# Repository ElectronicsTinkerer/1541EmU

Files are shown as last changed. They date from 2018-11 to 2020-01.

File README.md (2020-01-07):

# 1541EmU
Source code and eagle files for the 1541 Emulator
<hr>

 _Description_
 
  The 1541EmU is a 1541 emulator for the c64. It is based on the ATMEGA328P-PU and interfaces over the IEC bus. Files are stored on a micro SD card formatted to FAT32 using the 8.3 file name format. Included is a drive reset button that resets the drive, but not the computer. There is also a solder jumper to enable reset-by-computer, which allows the c64's reset line to reset the drive.
 <br> 
 I have a demo <a href="https://youtu.be/4uivsbCX4fI">here</a>. (https://youtu.be/4uivsbCX4fI)
  
 _Features_
 
  * Save and load files with almost any filename (ASCII Characters only)
  * Change file order on disk (Through a computer)
  * <code>LOAD "*",8</code> is allowed
  * View directory
  * Overwrite existing files on disk
  * Auto initialization of filename translation file (DIR)
  * Cassette interface pass through connector.
  * ICSP and Tx/Rx headers
  * Power and status LEDs
  * Compatible with the Arduino IDE

# Board
Latest board revision: 1.1 on September 9, 2018
  (Note: there is no official revision 1.0)
  
  1) Checked schematic, part numbers, and part footprint sizing.
  2) Fixed board dimension issue
  
# Source
Latest revision: EFS1.00 (Extended File System v1.00) on October 23, 2018
  
  1) Added the "DIR" file that translates the expected filename from the c64 to the actual name that is stored on the SD
  2) Fixed "DEVICE NOT PRESENT ERROR" (as far as I can test the drive)

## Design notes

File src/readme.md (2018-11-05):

Included in the /src directory are the various revisions of the source for the 1541EmU.

The latest revision is EFS v1.00

In the /src/EFS1.00 directory is an example DIR file in addition to the arduino source

Revision history is below (Newest to Oldest):

	EFS1.00

	v3.25

	v2.18 (Contains part of v1.00 at bottom comments)

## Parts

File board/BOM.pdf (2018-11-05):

BOM

Page 1

Part | Unit Price | Total Price Number Needed | Notes:
Connectors
CEC* | $1.40 | 5 | $6.99 | 1 | Card edge connector, 2x6, 3.96mm spacing | Also can use these: 387-012-523-300
DIN 6 | $1.40 | 5 | $6.99 | 1 | DIN 6 connector, male
RJ11 Male | $0.10 | 100 | $9.99 | 1 | | https://www.amazon.com/dp/B06XV7J3KZ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
523-RJE01J4001 | $0.51 | 10 | $5.10 | 1 | RJ11 Female (**CHECK**) | https://www.mouser.com/ProductDetail/Amphenol-Commercial-Products/RJE01J4001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

Sockets
571-1-2199298-9 | $0.60 | 10 | $6.03 | 1 | 28 Pin DIP socket, 7.62 Row Spacing, 2.54 Pitch | https://www.mouser.com/ProductDetail/TE-Connectivity/1-2199298-9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
47334-0001 | $3.15 | 1 | $3.15 | 1 | MicroSD Holder, Push-Push, SMD | https://www.mouser.com/ProductDetail/Molex/47334-0001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

IC
LP2950-33LPRE3 | $0.38 | 10 | $3.76 | 1 | 3.3v REG | https://www.mouser.com/ProductDetail/Texas-Instruments/LP2950-33LPRE3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
ATMEGA328P-PU | $2.14 | 5 | $10.70 | 1 | Main controler, DIP28 | https://www.mouser.com/ProductDetail/Microchip-Technology-Atmel/ATMEGA328P-PU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

Passive
ULD1H2R2MDD1TD | $0.09 | 100 | $9.00 | 1 | 2.2uF | https://www.mouser.com/ProductDetail/Nichicon/ULD1H2R2MDD1TD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
USP1HR22MDD | $0.21 | 10 | $2.07 | 2 | 0.22uF | https://www.mouser.com/ProductDetail/Nichicon/USP1HR22MDD?qs=%2fha2pyFadujuMoPc7crJw6l9tVyhaXQnGDLoTOhhVrE%3d
K220J10C0GF5UH5 | $0.04 | 50 | $1.75 | 2 | 22pF | https://www.mouser.com/ProductDetail/Vishay-BC-Components/K220J10C0GF5UH5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
OJ4715E-R52 | $0.01 | 100 | $1.00 | 2 | 470 Ohm | https://www.mouser.com/ProductDetail/Ohmite/OJ4715E-R52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
299-2.2K-RC | $0.12 | 1 | $0.12 | 3 | 2.2k Ohm | https://www.mouser.com/ProductDetail/Xicon/299-22K-RC?qs=sGAEpiMZZMu61qfTUdNhGzmcydQ1pJoanehw0NWTJkc%3d
299-3.3K-RC | $0.12 | 1 | $0.12 | 3 | 3.3k Ohm | https://www.mouser.com/ProductDetail/Xicon/299-33K-RC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
299-4.7K-RC | $0.01 | 200 | $2.20 | 3 | 4.7k Ohm | https://www.mouser.com/ProductDetail/Xicon/299-47K-RC?qs=sGAEpiMZZMu61qfTUdNhG%2fbdyz6pU6a%252bfqpVSzaacno%3d
299-1M-RC | $0.12 | 1 | $0.12 | 1 | 1M Ohm | https://www.mouser.com/ProductDetail/Xicon/299-1M-RC?qs=sGAEpiMZZMu61qfTUdNhG1aMK7XKB77EzBMns1d2vjU%3d
LFXTAL027945Bulk | $0.18 | 1 | $0.18 | 1 | 16MHz Crystal | https://www.mouser.com/ProductDetail/IQD/LFXTAL027945Bulk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
833-1N914B-TP | $0.18 | 100 | $2.70 | 1 | Diode for reset 1N914 | https://www.mouser.com/ProductDetail/Micro-Commercial-Components-MCC/1N914B-TP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

Indicators
859-LTL-1CHEE | $0.06 | 100 | $6.40 | 1 | Red LED | https://www.mouser.com/ProductDetail/Lite-On/LTL-1CHEE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
859-LTL-1CHG | $0.06 | 100 | $6.40 | 1 | Green LED | https://www.mouser.com/ProductDetail/Lite-On/LTL-1CHG?qs=sGAEpiMZZMuCm2JlHBGefiNuiN6kU%2fJslYHv14s%2f9OY%3d

Misc
Wire | $0.17 | 33 | $5.45 | 1 | Assuming 9" used per unit | https://www.amazon.com/Bistras-Telephone-Extension-Machine-Answering/dp/B075JRX7XK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
SPST Pushbutton | $0.19 | 10 | $1.86 | 1 | Reset Switch | https://www.mouser.com/ProductDetail/Panasonic/EVQ-PAC05R/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
Screw | | | | 2 | Standoff
Nut | | | | 4 | Standoff
Rubber Foot | | | | 2 | Standoff

Board
85x40mm | $1.90 | 10 | $19.00 | 1 | PCB Board, Green Soldermask
Total | $13.13 | 963 | $111.08 | $13.88

Number
Purchased

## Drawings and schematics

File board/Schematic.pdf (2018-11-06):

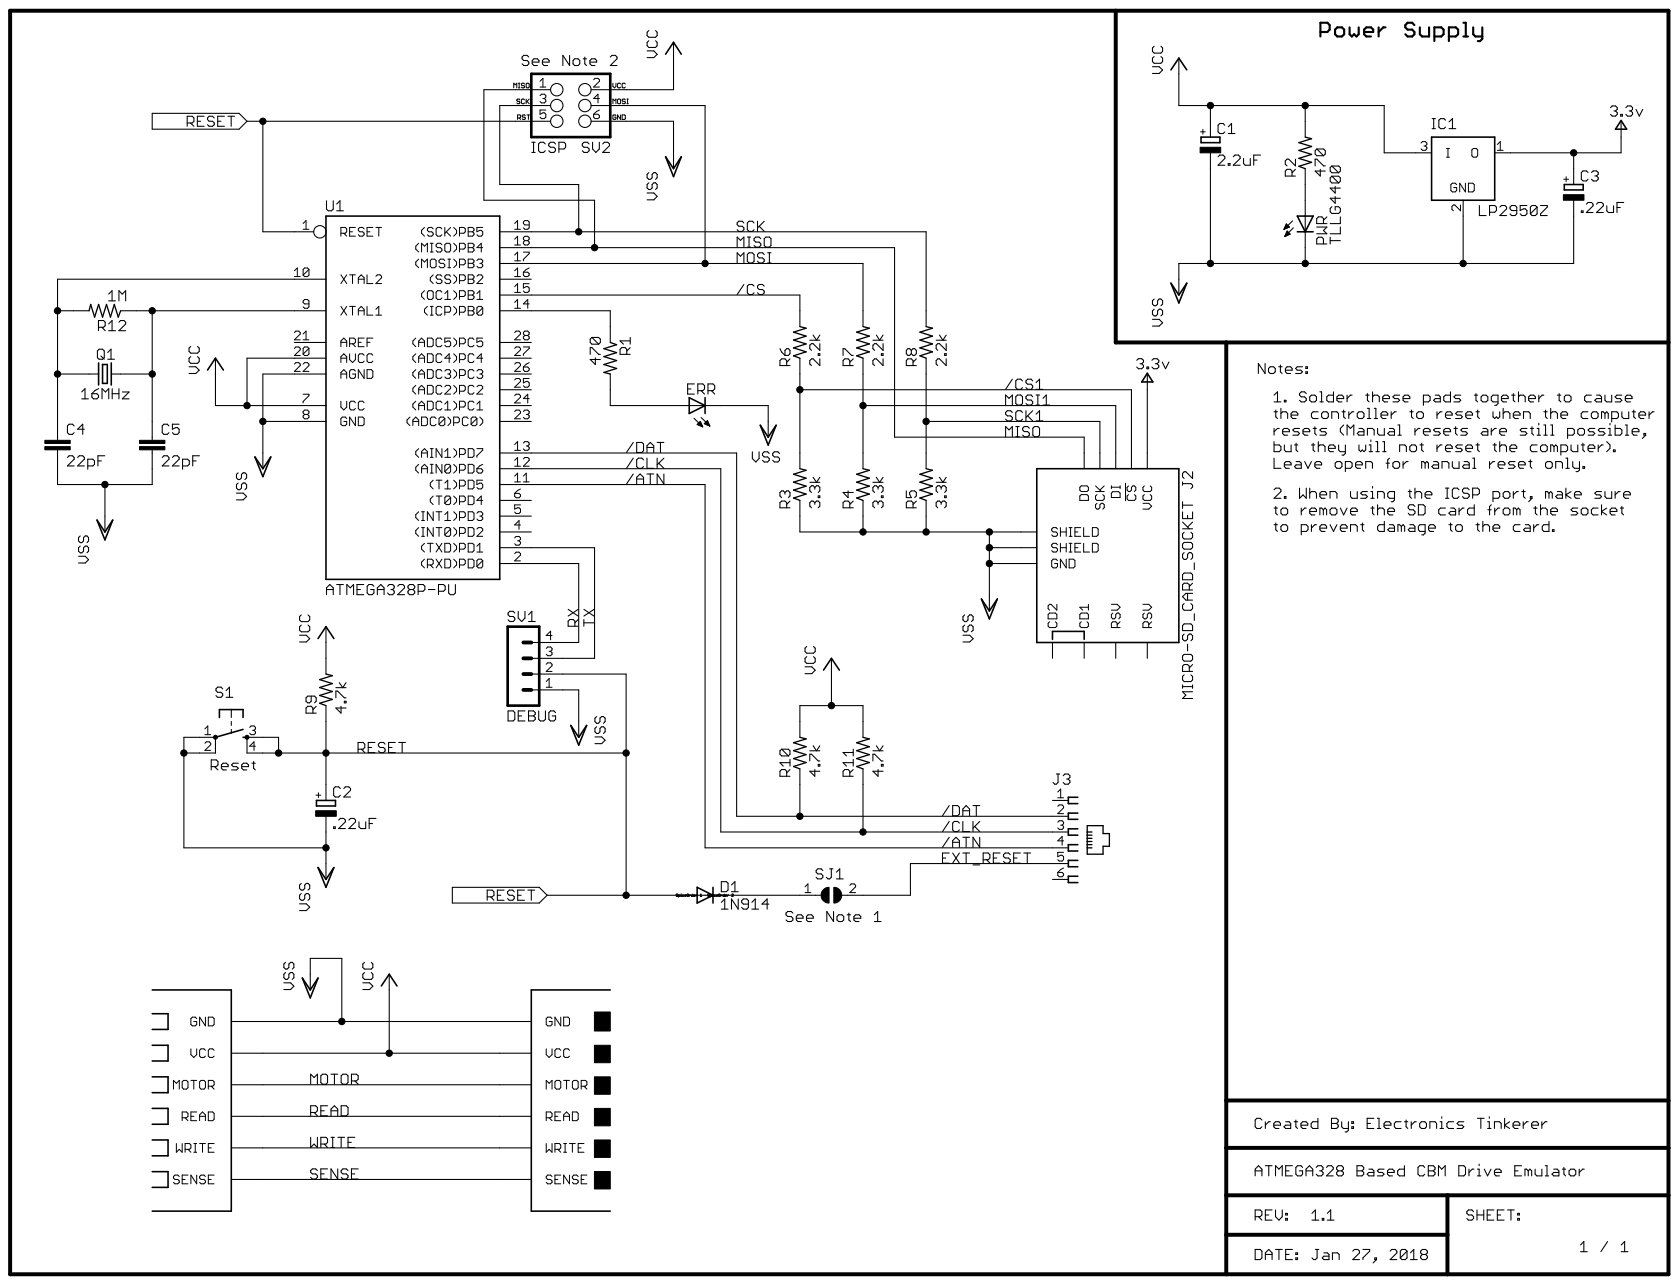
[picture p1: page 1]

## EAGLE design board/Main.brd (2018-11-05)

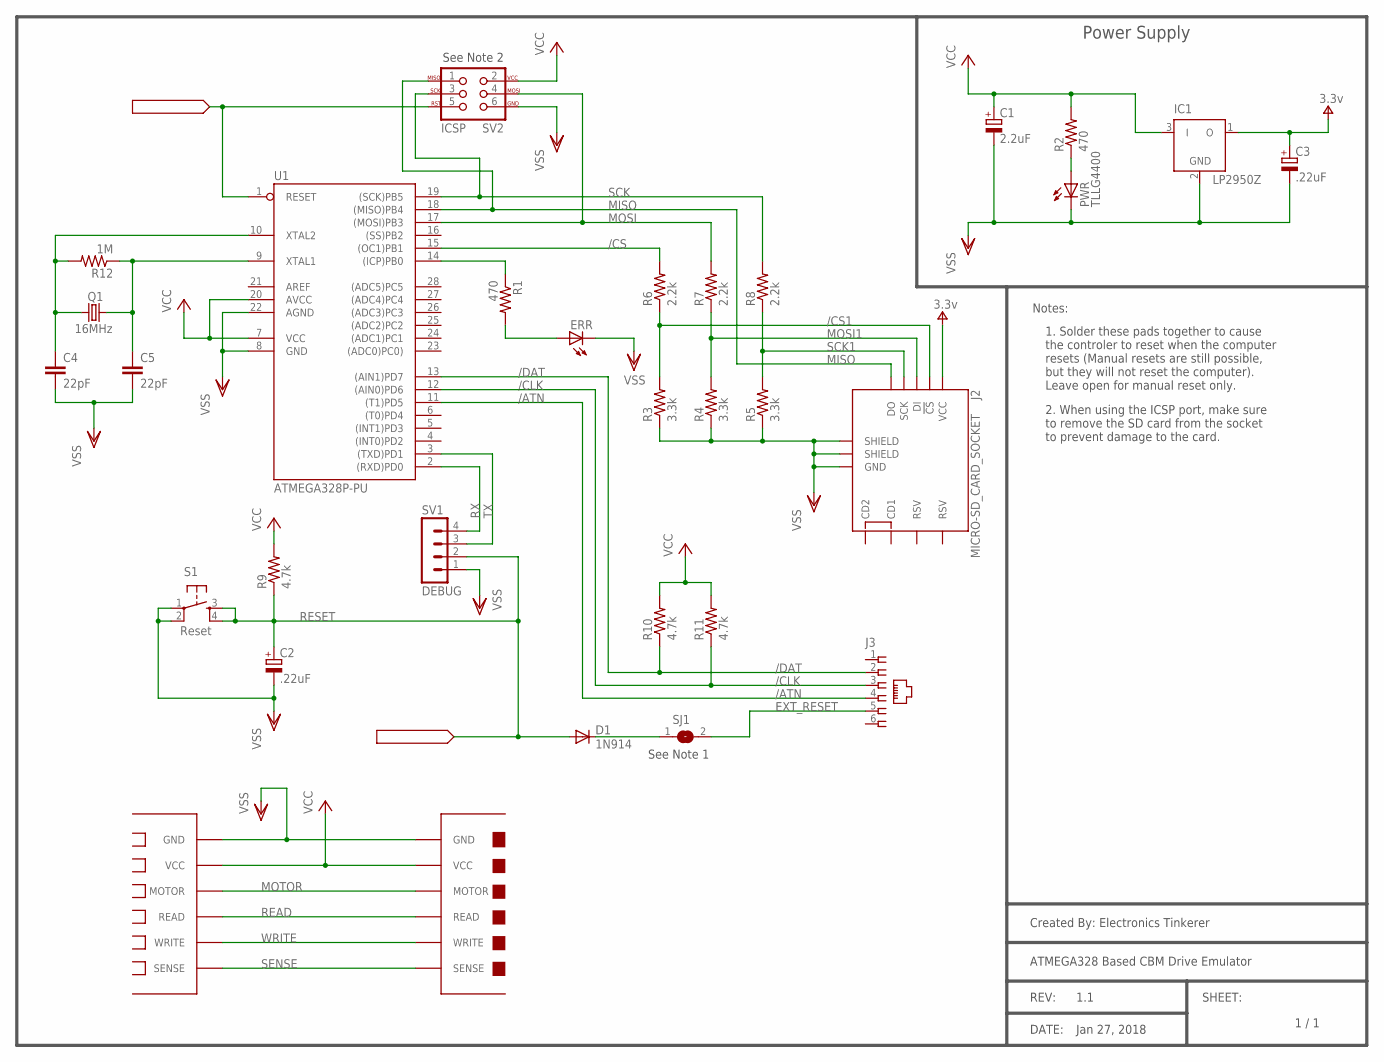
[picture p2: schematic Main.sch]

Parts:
C1: 2.2uF; E2-5
C2, C3: .22uF; E1,5-4
C4, C5: 22pF; C050-024X044
D1: 1N914; DO41-5
ERR: TLLR4400; LED3MM
IC1: LP2950Z; TO92
J2: MICRO-SD_CARD_SOCKET; MICRO-SD-SOCKET
J3: 520470-3
PWR: TLLG4400; LED3MM
Q1: 16MHz; HC49/S
R1, R2: 470; 0204/5
R3, R4, R5: 3.3k; 0204/5
R6, R7, R8: 2.2k; 0204/5
R9, R10, R11: 4.7k; 0204/5
R12: 1M; 0204/5
S1: DTS-6
SJ1: SJ
SV1: DEBUG; MA04-1
SV2: AVR_SPI_PROG; 2X3
U1: ATMEGA328P-PU; DIL28-3
U$1: CASSETT-BOARDCEC-6; SOLDER-PADS_3,96-M
U$2: CASSETT-CON; SOLDER-PADS_3,96-F

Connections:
/ATN: J3.4, U1.11 ((T1)PD5)
/CLK: J3.3, R11.1, U1.12 ((AIN0)PD6)
/CS: R6.2, U1.15 ((OC1)PB1)
/CS1: J2.CS (!CS), R3.2, R6.1
/DAT: J3.2, R10.1, U1.13 ((AIN1)PD7)
EXT_RESET: J3.5, SJ1.2
MISO: J2.DO, SV2.1, U1.18 ((MISO)PB4)
MOSI: R7.2, SV2.4, U1.17 ((MOSI)PB3)
MOSI1: J2.DI, R4.2, R7.1
MOTOR: U$1.MOTOR, U$2.MOTOR
unnamed: R1.1, U1.14 ((ICP)PB0)
unnamed: PWR.A, R2.1
unnamed: ERR.A, R1.2
unnamed: D1.C, SJ1.1
unnamed: C4.1, Q1.1, R12.2, U1.10 (XTAL2)
unnamed: C5.1, Q1.2, R12.1, U1.9 (XTAL1)
READ: U$1.READ, U$2.READ
RESET: C2.+, D1.A, R9.1, S1.3, S1.4, SV1.2, SV2.5, U1.1 (RESET)
RX: SV1.4, U1.2 ((RXD)PD0)
SCK: R8.2, SV2.3, U1.19 ((SCK)PB5)
SCK1: J2.SCLK (SCK), R5.2, R8.1
SENSE: U$1.SENSE, U$2.SENSE
TX: SV1.3, U1.3 ((TXD)PD1)
V+: C3.+, IC1.1 (O), J2.VCC
VCC: C1.+, IC1.3 (I), R2.2, R9.2, R10.2, R11.2, SV2.2, U1.7 (VCC), U1.20 (AVCC), U$1.VCC, U$2.VCC
VSS: C1.-, C2.-, C3.-, C4.2, C5.2, ERR.K (C), IC1.2 (GND), J2.GND, J2.GND1 (SHIELD), J2.GND3 (SHIELD), PWR.K (C), R3.1, R4.1, R5.1, S1.1, S1.2, SV1.1, SV2.6, U1.8 (GND), U1.22 (AGND), U$1.GND, U$2.GND
WRITE: U$1.WRITE, U$2.WRITE

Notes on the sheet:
Power Supply
See Note 1
1. Solder these pads together to cause the controler to reset when the computer resets (Manual resets are still possible, but they will not reset the computer). Leave open for manual reset only.
Notes:
Created By: Electronics Tinkerer
ATMEGA328 Based CBM Drive Emulator
REV:
1.1
DATE:
Jan 27, 2018
SHEET:
1 / 1
2. When using the ICSP port, make sure to remove the SD card from the socket to prevent damage to the card.
See Note 2

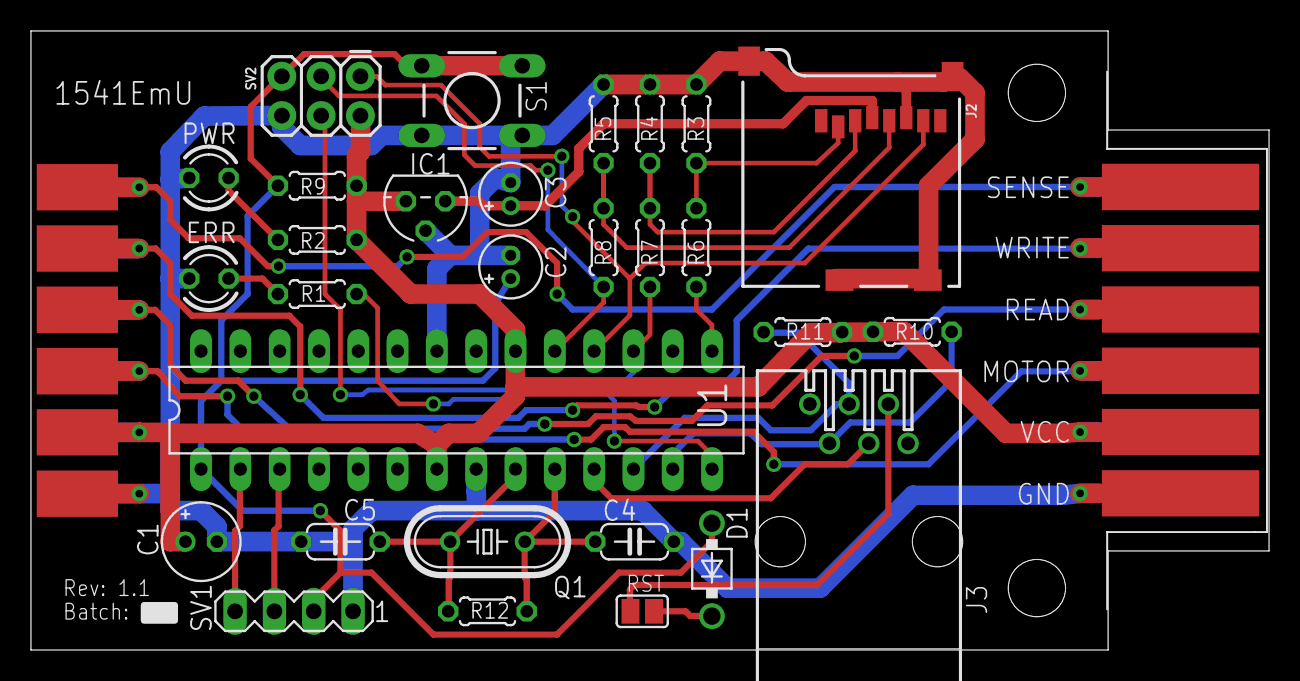
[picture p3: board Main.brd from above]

Board: 2 copper layers, 80.0 x 40.0 mm, 31 parts (0 on the bottom side), 27 nets.

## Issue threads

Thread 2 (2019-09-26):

Not a Issue but a question.

Therealjosephchrzempiec, 2019-09-26:
Hello i was looking at your code and I was wondering what is the ESP8266 for? Sorry  a little lost to see that in the code.

Joseph

ElectronicsTinkerer, 2020-01-07:
Hello,
Sorry about the slow response, I am pretty new to GitHub and did not realize that there was the "Issues" tab. Anyway, that's a good question. I originally had planned to add an ESP 8266 to the board later on to give the board the ability to connect over WiFi. In v3.25 of the code, I still had the comments (and some code) indicating that the ESP 8266 was still on board and accessible by addressing device 16. As of right now, EFS v1.00 is the latest version of the code that I have released, so make sure that you are running that one. The older versions (v3.xx and v2.xx) don't have support for long filenames, so I would definitely recommend the newer one (although it is a bit more complex in terms of accessing a file). (I believe) I have removed all of the ESP 8266 code from EFS v1.00, so I wouldn't worry about it.

TL;DR: The ESP 8266 was included in older versions of the code, as I had planned on adding support, however, I have removed it from the latest version to simplify the code. So, it is not needed for it to work.

Hope that helps!

SuperNeotendo, 2023-09-27:
just an idea what was in my head: what if you compile this code on the ESP32 and add 6502/CIA/VIA Emulation?

ElectronicsTinkerer, 2023-10-10:
That could be an interesting expansion to the project. It might even allow fast loaders. I do have a instruction-resolution [65816 emulator](https://github.com/ElectronicsTinkerer/816CE) that could be dropped in as long as the software did not require any undocumented opcodes or cycle-specific timings.

SuperNeotendo, 2023-10-11:
yeah, i found an C64 emulator for ESP32 maybe you can use some code from there, 6502 emulation atleast

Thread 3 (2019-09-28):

File not laoding in file browser program.

Therealjosephchrzempiec, 2019-09-28:
Hello i uploaded your sketch and typed out everything. Granted I'm still new to commodore but i have a problem. When i booted up my commodore i typed in LOAD"$",8 then it said ready, Follow that by a LIST command and i was able to see the files on the SD card. When i tyoe in LOAD"FB64",8 that is the file browser program on the sd card i found online. When i type that in said ready. The i typed in RUN command it and it open the file browser with a background. Everything looked okay but one problem. None of the files was displaying in the file browser. Can you please help me?

Joseph

ElectronicsTinkerer, 2020-01-07:
You might be having a compatibility issue with the code. When I wrote this, I had only designed it to work with BASIC commands for strictly SAVEing/LOADing files. As a result, many programs that use other means to read a file (i.e. OPEN/CLOSE) might not work.

Other than compatibility, what version of the source are you running? Version EFS v1.00 is the latest.
Also, is there a flash code on the drive emulator? I believe that I put the descriptions of each code near the top of the source.

Let me know if you need anything else. I am not currently actively working on this project, but I am more than happy to pull it out and take a look if you need some help!

Zibri, 2020-05-15:
it would be great to make it emulate tracks/sectors and G64 format as well.. but maybe arduino is not powerful enough for that...hmmm

Zibri, 2020-05-15:
perhaps "borrowing" the code from other projects on github like https://github.com/pi1541/Pi1541

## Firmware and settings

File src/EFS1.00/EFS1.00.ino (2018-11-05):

/*
Schematic:

 VCC -+-`/\/\/'---+
      |   4.7k    |
      +-`/\/\/'-+ |
                | |
------+     +---+ |     +---------
  A   |     |     |     |
  R  6| ----|-----+---- | /CLK
  D   |     |           |       C
  U  7| ----+---------- | /DAT  6
  I   |                 |       4
  N  5| --------------- | /ATN
  O   |                 |
      |                 +---------
      |
      |                 +---------
     9| --------------- | /CS SD
      |                 +---------
      |
      |       4.7k      //
     8| ----`/\/\/'---[>|-----+
      |              ERROR    |             
      |                      VSS            
------+
*/

// include the SD library
#include <SPI.h>
#include <SD.h>

#define SD_CS 9

//Data Lines from the c64
#define ATN 5
#define CLK 6
#define DAT 7

//Error LED Pin
#define ERRLED 8

//Device numbers for ARDUINO SD DRIVE and ESP8266 Interface
#define DRIVE_NUMBER 8    //Device #8 is DISK

#define FALSE 0
#define TRUE 1

bool eoi = FALSE;           //EOI for receiving
bool myeoi = FALSE;         //EOI for sending
byte byteIn = 0x00;         //Current Byte received
bool haveGotData = FALSE;   //Did get data yet?
String filename = "";       //String to represent File names
String filenameCon = "";    //Filename used as temporary buffer in locating the filename in the dir file
char fileByte = 0;          //Used in parsing the directory file
char filenameByte = 0;      //Used in conversion of bytes to ASCII
char fileBuffer = 0;        //Used as a buffer when receiving files from the computer
unsigned long fileSize = 0; //Current character counter for sending files, used to find the EOI of a file
bool fileOverwrite = FALSE; //Determines if a file can be overwritten
bool fileIsDir = FALSE;     //Used to determine if a file is a directory or not, see (load "*",8)
int timeTaken = 0;          //Used in timing a frame handshake when sending bytes from device
byte deviceSelect = 0;      //Device Number selected by the computer
byte openChannel = 0;       //Current channel opened by the computer



/**********************************************
 *          STATUS AND COMMAND CODES          *
 **********************************************/
#define RESET 0
#define ATN_TRUE 1
#define LISTEN 2
#define UNLISTEN 3
#define TALK 4
#define UNTALK 5
#define OPEN_CAN 6
#define CLOSE 7
#define OPEN 8

#define LOAD 9
#define SAVE 10


byte currentStatus = RESET;   //What mode we are in
byte currentCommand = RESET; //Loading or Saving?


/*******************************************
 *          ERROR LED FLASH CODES          *
 *******************************************/
 
#define OVERWRITE_ERROR 2   //Two flashes if a file is attempted to be overwritten without the proper syntax ("@0:")
                            //Use "@0:" in front of the filename to overwrite existing file
#define FRAME_ERROR 3       //Computer did not respond with a frame handshake within 1ms

#define SD_ERROR 4          //SD card failed to initialize

byte errorCode = RESET;     //Error codes for LED


File root;        //Used as the root directory when searching for first file on disk
File tempFile;    //Setup temporary file

  
void setup() {
  //start serial connection
  Serial.begin(115200);
  while (!Serial) {
    ; // wait for serial port to connect. Needed for native USB port only
  }
  
  if (!SD.begin(SD_CS)) {   //Start SD Driver
    Serial.println("SD initialization failed!");
    errorCode = SD_ERROR; //Set flash code and flash it
    flashError(errorCode);
  }
  if (!SD.exists("dir")) {
    //If the dir file is not on the card, auto-generate one
    Serial.println("dir NOT FOUND! Generating a new one...");
    File dir = SD.open("/dir", FILE_WRITE);
    dir.print("#SD dir file auto generated\r#Line-endings are macintosh-format (CR)\r#\r#Format:\r#[FILENAME EXPECTED BY C64]`[ACTUAL FILENAME ON DISK];");
    dir.close();
  }
  Serial.println("SD initialization done.");
  //Configure all input pullup resistors
  //These can be used as resistive outputs
  pinMode(ATN, INPUT_PULLUP); 
  digitalWrite(CLK, LOW);
  pinMode(CLK, INPUT);  //Allows it to be pulled low by other devices on the line
  digitalWrite(DAT, LOW);
  pinMode(DAT, INPUT);  //Allows it to be pulled low by other devices on the line

  //Reset Error LED
  pinMode(ERRLED, OUTPUT);
  digitalWrite(ERRLED, LOW);

  
  Serial.println();
  Serial.println("Ready. vEFS1.00");
}

void loop() {
  
  if ((digitalRead(ATN) == LOW) && (currentStatus < OPEN)) {  //Computer is requesting to communicate
                              //&& (digitalRead(CLK) == LOW)
    byte currentByte = 0;
    do {
      Serial.println("ATN");
      currentByte = getByte(); //Sets DATA TRUE
      Serial.println(currentByte, HEX);
      if (currentByte < 0x3f) {   //If receiving a listen command, listen
        deviceSelect = currentByte - 0x20;  //Remove the base address from the command and set it as the device number
        currentStatus = LISTEN;
        currentCommand = SAVE;    //Load a file
      }
      else if (currentByte == 0x3f) {   //UNLISTEN
        currentStatus = UNLISTEN;
      }
      else if (currentByte < 0x4f && currentByte > 0x3f) {  //TALK
        deviceSelect = currentByte - 0x40;  //Remove the base address from the command received
        currentStatus = TALK;
        currentCommand = LOAD;    //Save a file
      }
      else if (currentByte == 0x5f) { //UNTALK
        currentStatus = UNTALK;
      }
      else if (currentByte < 0x70 && currentByte >= 0x60) {   //OPEN
        openChannel = currentByte - 0x60;   //Set the current channel
        currentStatus = OPEN_CAN;
      }
      else if (currentByte < 0xf0 && currentByte >= 0xe0) {   //CLOSE
        openChannel = 0;  //Reset current channel
        currentStatus = CLOSE;
      }
      else if (currentByte <= 0xff && currentByte >= 0xf0) {   //OPEN
        openChannel = currentByte - 0x60;   //Set the current channel
        currentStatus = OPEN;
      }
      //Serial.println(currentStatus);
    } while ((digitalRead(ATN) == LOW) and (currentStatus < OPEN));  //Loop until end of commands
  }
  
  else if (currentStatus == OPEN_CAN and deviceSelect == DRIVE_NUMBER) {   //Lets open a file to send to the computer  
     
    if (currentCommand == LOAD) {    //If we are in load mode
      Serial.println("LOAD");
      turnAroundSlave();  //Turn the bus around

      if (filename == "$") {            //User wants to see a directory
        sendDir();    //Send the directory
      }
      else if (filename == "*") {       //User wants to load first file on disk
        root = SD.open("/dir");            //Open root directory
           
        do {      
          fileByte = root.read();
          if (fileByte == '#') {  //Skip Comments
            while (root.read() != 0x0d)  //Loop until end of line
              if (root.position() == root.size())
                break;  //Prevent the arduino from being stuck in an infinite loop!
          }
          else if (fileByte == 0x0d) {
            
          }
          else {
            while (root.read() != '`') {
              //Loop until the first file is found
              if (root.position() == root.size())
                break;  //Prevent the arduino from being stuck in an infinite loop!
            }

            filename = "";  //Clear the filename given by the c64
            //Replace filename by the file name in the dir file.
            while (root.peek() != ';') {
              filenameByte = root.read();
              filename.concat(filenameByte);
              if (root.position() == root.size())
                break;  //Prevent the arduino from being stuck in an infinite loop!
              //Serial.println(filenameByte);
            } 
            break;  //Stop checking the dir file table
          } 
          
        } while (root.size()-1 > root.position());  //Loop until end of directory file
        root.close();

        sendFile(filename);             //Send the file
      }
      else {    //Check to see if the file exists on the SD card, otherwise, turn around again to indicate an error situation
                //Get the filename from the dir file and send the file
        sendFile(getFilenameFromDir(filename)); 
      }
      
      //If there was no file with that name, this Master turnaround will indicate an error condition, 
      // but if the file was found, it will return the arduino to the listener and the computer to the talker
      turnAroundMaster(); 
    }
    
    else if (currentCommand == SAVE) {
      Serial.println("SAVE");
      filenameCon = getFilenameFromDir(filename);
      Serial.println(filenameCon);
      if (SD.exists(filenameCon)) {   //Overwrite an existing file
        if (fileOverwrite == TRUE) {  //Yes, the file can be overwritten
          Serial.println("EXISTS");
          SD.remove(filenameCon);    //Delete the existing file
          writeFile(filenameCon);    //Write to the file
          fileOverwrite = FALSE;  //Reset file overwrite enable
          
        } else {    //If trying to overwrite a file without proper syntax ("@0:"), error
          errorCode = OVERWRITE_ERROR;    //Set error code
          flashError(errorCode);          //Flash error code
        }
      }
      else if (!SD.exists(filenameCon)) {  //Create new file
        Serial.println("DOES NOT EXIST");
 
        writeFile(createDirEntry(filename)); //Create and write to the file
        //tempFile = SD.open(filename, FILE_WRITE); //Put new file on SD
        //tempFile.close();   //Close the file and save changes
      }
    }

    currentStatus = RESET;    //Reset the current Status
    currentCommand = RESET;
  }
            
  else if (currentStatus == OPEN and deviceSelect == DRIVE_NUMBER) { //Get the filename to be opened if the channel is 0 or 1
          
    Serial.println("OPENFile");
    filename = "";                    //Clear filename
    do {                              //Loop until entire filename has been received
      filenameByte = getByte();       //Convert the byte to a character
      filename.concat(filenameByte);  //Convert all bytes of the filename to a string
    } while (eoi == FALSE);           //Keep receiving bytes until the entire file name has been received (eoi == TRUE)
   
    if (filename.startsWith("@0:")) { //If the filename begins with "@0:" then it is intended to overwrite the existing file
      fileOverwrite = TRUE;           //Set flag to allow overwrites
      filename.remove(0,3);           //Remove the first three characters from the filename string
    }
    Serial.println(filename);
  
    currentStatus = RESET;            //Reset the current Status
  }
  
  else if (currentStatus == UNLISTEN) {
    Serial.println();
    currentStatus = RESET;          //Reset the current Status
  }

}

String createDirEntry(String tempName) {    //Creates a new entry in dir file
  root = SD.open("dir", FILE_WRITE);            //Open root directory
  root.seek(root.size()); //Go to end of file
  //Insert the entry into the dir table
  root.write(0x0d);
  root.print(tempName);
  root.print('`');
  root.print(tempName.substring(0,8));  //Use only the first 8 characters of the filename as the actual filename
  root.print(';');
  root.close();   //Close 'dir
  return tempName.substring(0,8);   //Return the name of the file on disk
}
String getFilenameFromDir(String tempName) {
  root = SD.open("/dir");            //Open root directory
           
  do {      
    fileByte = root.read();
    if (fileByte == '#') {  //Skip Comments
      while (root.read() != 0x0d) //Loop until end of line
        if (root.position() == root.size())
          break;  //Prevent the arduino from being stuck in an infinite loop!
    }
    else if (fileByte == 0x0d) {
      
    }
    else {
      filenameCon = "";  
      root.seek(root.position()-1); //Backup one character in the file
      //Loop to check the filename in the next entry
      while (root.peek() != '`') {
        filenameByte = root.read();
        filenameCon.concat(filenameByte);
        if (root.position() == root.size())
          break;  //Prevent the arduino from being stuck in an infinite loop!
        //Serial.println(filenameByte);
      } 
      filenameCon.toUpperCase();
      Serial.println(filenameCon);
      if (filenameCon != tempName) {
        if (root.position() == root.size())
          break;  //End of file means no more entries in the file!
        while (root.read() != 0x0d) { //Loop until end of line
          if (root.position() == root.size()) {  //Make sure not at end of file
            tempName = "FILENOTF.ONF";  //ERR: File not found!
            break;  //Done!
          }
        }
        continue; //If not the correct file, check again
      }
  
      root.read();
      tempName = "";  //Clear the filename given by the c64
      //Replace filename by the file name in the dir file.
      while (root.peek() != ';') {
        filenameByte = root.read();
        tempName.concat(filenameByte);
        //Serial.println(filenameByte);
      } 
      break;  //Stop checking the dir file table
    } 
  } while (root.position() != root.size());  //Loop until end of directory file

  root.close();   //Close 'dir'

  return tempName;
}

void sendDir() {      //Creates a directory and sends it
  digitalWrite(ERRLED, 1);
  unsigned int currentOffset = 0x0801;  //Address of BASIC line
  unsigned int lineNumber = 10;         //Line number
  String tempName = "";                 //Temporary file name variable
  String tempSize = "";                 //Stores the size of the file
  unsigned int lineLength = 0;          //Length of line
  unsigned int seekPos = 0;             //Last seek position in file before closing and opening the other file to get size
  
  shiftByteOut(lowByte(currentOffset), FALSE);   //Send the currentOffset - this is the first two bytes (little-endian) for the start of a .PRG file
  shiftByteOut(highByte(currentOffset), FALSE); 


  //Output the title line:  "10 FILE                SIZE"
  currentOffset += 0x1F;     //Increment current offset to next line of BASIC program
  shiftByteOut(lowByte(currentOffset), FALSE);   //CurrentOffset
  shiftByteOut(highByte(currentOffset), FALSE); 

  shiftByteOut(lowByte(lineNumber), FALSE);   //Send line number
  shiftByteOut(highByte(lineNumber), FALSE); 

  sendStringofBytes(" FILE                 SIZE");  //Send file header
  
  shiftByteOut(0x00, FALSE);                  //Send end-of-line marker

  root = SD.open("/dir"); //Open root directory
           
  do {      
    fileByte = root.read();
    if (fileByte == '#') {  //Skip Comments
      while (root.read() != 0x0d) //Loop until end of line
        if (root.position() == root.size())
          break;  //Prevent the arduino from being stuck in an infinite loop!
    }
    else if (fileByte == 0x0d) {  //Skip line ending
      
    }
    else {
      tempName = "";  
      root.seek(root.position()-1); //Backup one character in the file
      if (root.peek() == ';')
        root.seek(root.position()+2); //Cuts off ';\r' from filename
      //Loop to check the filename in the next entry
      while (root.peek() != '`') {
        filenameByte = root.read();
        tempName.concat(filenameByte);
        if (root.position() == root.size())
          break;  //Prevent the arduino from being stuck in an infinite loop!
        //Serial.println(filenameByte);
      } 
      
  
      root.read();
      filenameCon = "";  //Clear the filename given by the c64
      //Replace filename by the file name in the dir file.
      while (root.peek() != ';') {
        filenameByte = root.read();
        filenameCon.concat(filenameByte);
        if (root.position() == root.size())
          break;  //Prevent the arduino from being stuck in an infinite loop!
        //Serial.println(filenameByte);
      } 
      seekPos = root.position();  //Save current search position
      root.close();               //Close the dir file
      File entry = SD.open(filenameCon);  //Open the file to get filesize
      tempSize = entry.size();              //Get the size of current file
      currentOffset += 27 + tempSize.length();   //Find the length of the current line and add it to the current offset (The 20 is for the number of extra bytes - next line offset, linenumber, SPACE at beginning of line, filename and following spaces, and ending NULL)

      shiftByteOut(lowByte(currentOffset), FALSE);  //Send current offset
      shiftByteOut(highByte(currentOffset), FALSE);

      lineNumber++;
      shiftByteOut(lowByte(lineNumber), FALSE);  //Send line number
      shiftByteOut(highByte(lineNumber), FALSE);


      shiftByteOut(0x20, FALSE);    // Add space at beginning of line

      tempName.toUpperCase();
      sendStringofBytes(tempName);  //Send Filename

      for (int spcCntr = 0; spcCntr <= 20-tempName.length(); spcCntr++) { //The 20 is the width, in characters, of the NAME column on the directory
        shiftByteOut(0x20, FALSE);    //Send enough spaces to move position to beginning of the SIZE column on screen
      }
      sendStringofBytes(tempSize);

      shiftByteOut(0x00, FALSE);      //Send end-of-line marker
      entry.close();                  //Close the currently open file
      root = SD.open("/dir");         //Re-open the dir file
      root.seek(seekPos);             //Return to original seek position
    } 
  } while (root.position() < root.size()-1);  //Loop until end of directory file

  root.close();   //Close 'dir'

  shiftByteOut(0x00, FALSE);   //Send the end-of-file indicator, both the 00 00 and the EOI
  shiftByteOut(0x00, TRUE);

  digitalWrite(ERRLED, 0);
}

void sendStringofBytes(String tempString) {   //Send a string to the computer (c64)
                                              //DOES NOT SEND AND EOI!!!!!!
  for (int strPrt = 0; strPrt < tempString.length(); strPrt++) {   //Iterate byte by byte until string is done
    shiftByteOut(tempString.charAt(strPrt), FALSE);   //Send the character
  }
}

void sendFile(String tempName) {
  Serial.println(tempName);
  digitalWrite(ERRLED, 1);
  tempFile = SD.open(tempName);   //Open selected file
  if (tempFile) {   //Hopefully, the file opened correctly, if not, exit if statements and return an error
    fileSize = tempFile.size() - 1; //Ge the size of the file minus one to know when to signal EOI
    Serial.println(fileSize);
    while (tempFile.available()) {      //Read until end of file
      if (fileSize == 0) {      //Check is EOI is needed
        myeoi = TRUE;                   //Signal that this is the last character
      }
      shiftByteOut(tempFile.read(), myeoi);  //Read byte from file then send it
      fileSize--;             //Increment the character counter
    }
    tempFile.close();         //Close the file
  }
  myeoi = FALSE;              //Reset EOI indicator
  digitalWrite(ERRLED, 0);
}

void writeFile(String tempFilename) {
  digitalWrite(ERRLED, 1);
  tempFile = SD.open(tempFilename, FILE_WRITE);   //Open the selected file
  
  fileBuffer = "";                //Clear filebuffer
  
  do {                            //Loop until entire file has been received
    fileBuffer = getByte();       //Convert the byte to a character
    tempFile.print(fileBuffer);   //Send character to file
  } while (eoi == FALSE);         //Keep receiving bytes until the entire file has been received (eoi == TRUE)             
  tempFile.close();               //Save the file and close it
  digitalWrite(ERRLED, 0);
}   

void turnAroundSlave() {    //Set DEVICE as Talker
  while (digitalRead(CLK) == LOW) { //Wait for computer to release the Clock Line
  }
  pinMode(DAT, INPUT);  //Release the Data line
  pinMode(CLK, OUTPUT); //Pull Clock true for starting position
}

void turnAroundMaster() {   //Set COMPUTER as Talker
  pinMode(DAT, OUTPUT);   //Pull the data true
  pinMode(CLK, INPUT);    //Release Clock 
}

byte getByte() {
  eoi = FALSE;  //Clear EOI flag
  pinMode(DAT, OUTPUT); //----------------------------------
  while (digitalRead(CLK) == LOW) {
  } //Wait for the computer to request to send a byte

  pinMode(DAT, INPUT);  //Release DATA line

  byte delayValue = 0;
  byte eoi_delay = 0;
  while (digitalRead(CLK) == HIGH && eoi_delay < 20) {    //Loop until Computer sets Clock line
    delayMicroseconds(10);
    eoi_delay++;    //Time it by this loop (1 cycle ~= 10 uS)
  }
  if (eoi_delay < 20) {
    byteIn = shiftByteIn();
  }
  else {
    eoi = TRUE;   //Set flag that this is an EOI
    pinMode(DAT, OUTPUT);   //Set DATA to true to signal that 
    delayMicroseconds(70);  //Allow computer to catch Acknowledge
    pinMode(DAT, INPUT);
    byteIn = shiftByteIn();
  }
  Serial.println(eoi);
  delayMicroseconds(20);
  pinMode(DAT, OUTPUT);  //Frame Handshake Acknowledge
  return byteIn;
}

byte shiftByteIn() {
  int temp = 0;
  byte myDataIn = 0;

  for (int i=0; i<=7; i++)
  {
    while (digitalRead(CLK) == HIGH) {   //Wait for the clock line to go to TRUE
    }
    while (digitalRead(CLK) == LOW) {  //Wait for clock line to go to FALSE
    }
    
    delayMicroseconds(4);   //Delay to make sure lines are stable
    temp = digitalRead(DAT);
    if (temp) {  
      //set the bit to 1
      myDataIn = myDataIn | (1 << i);
    } 
  }
  return myDataIn;
}
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

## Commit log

2018-11-05 Upload all files
    [Main.brd, Main.sch]
2018-11-06 Update Note 1 in schematic
    [Main.sch]

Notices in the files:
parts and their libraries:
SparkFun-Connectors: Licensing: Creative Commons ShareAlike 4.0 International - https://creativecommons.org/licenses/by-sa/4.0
